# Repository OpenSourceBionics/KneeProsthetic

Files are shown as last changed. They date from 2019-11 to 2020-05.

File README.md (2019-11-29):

# KneeProsthetic

Passive and powered leg prostheses are expensive and require access to specific equipment and technology, making them very inaccessible. Our objective is to build an open source powered prosthesis that is lightweight, inexpensive, and has a functional controller to be a foundation for striving engineers.

## Getting Started

This repository contains the preliminary code to manually control your powered prosthesis through both wired and wireless communication. 

### Prerequisites

* Arduino - latest edition
* Teensyduino - latest edition
* Python 2.7

* Raspberry Pi Zero W (x2 for wireless communication)
* Teensy 4.0

### Installing

* [Teensyduino Download Link](https://www.pjrc.com/teensy/td_download.html)
* [Arduino Download Link](https://www.arduino.cc/en/main/software)

## Running the tests

Explain how to run the  tests for this system

## Authors

* **Justin Francis** - *Initial work* - [jphran](https://github.com/jphran)
* **Palani Thangaraj** - *Initial work* - [palan-thangaraj](https://github.com/palani-thangaraj)

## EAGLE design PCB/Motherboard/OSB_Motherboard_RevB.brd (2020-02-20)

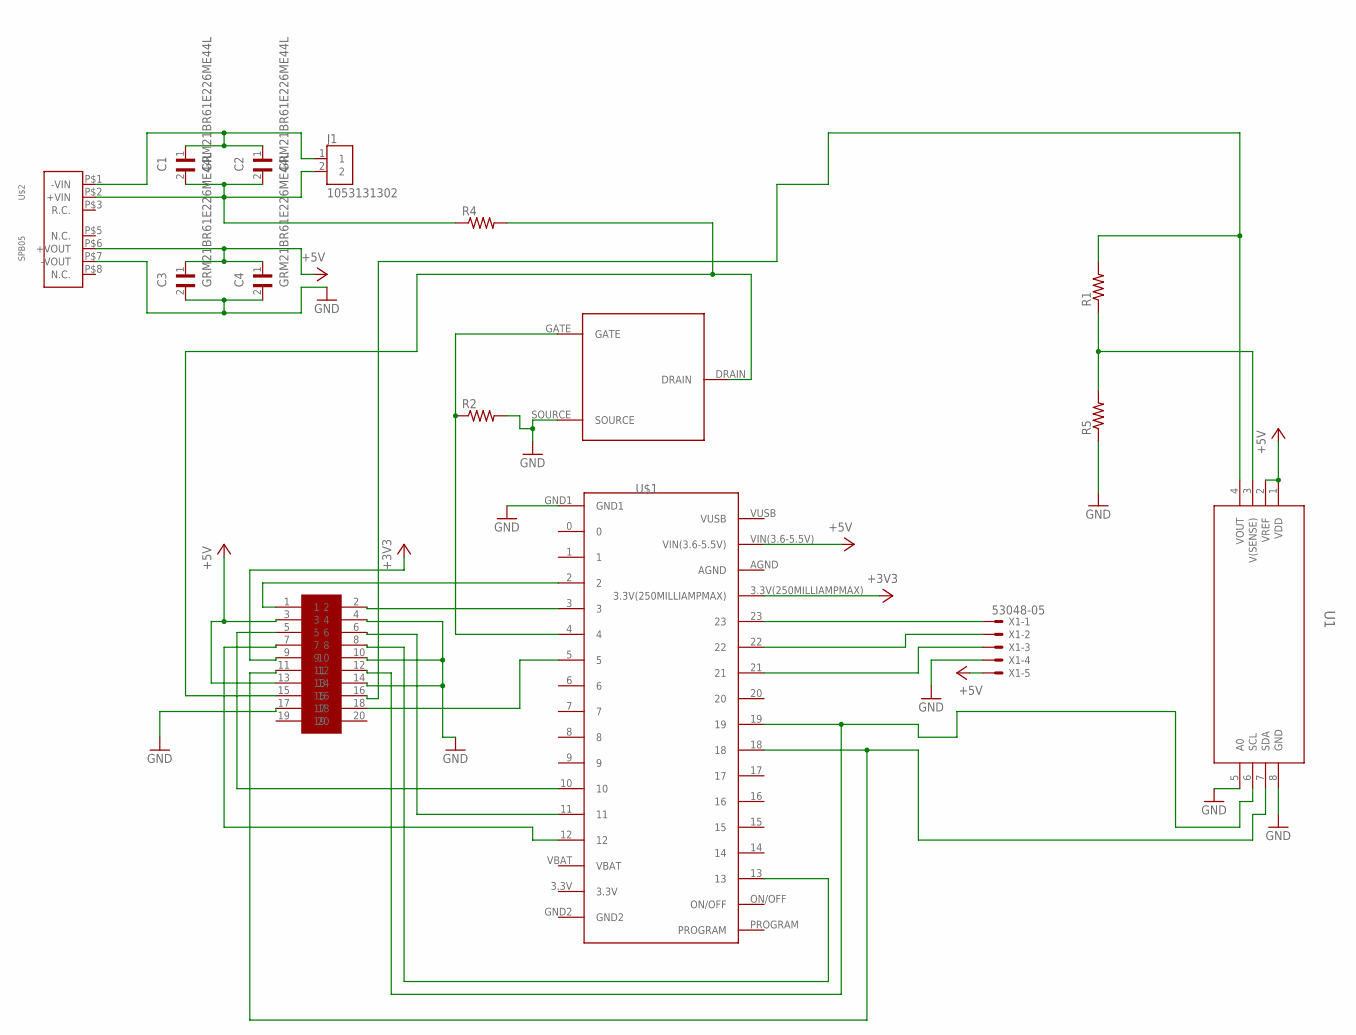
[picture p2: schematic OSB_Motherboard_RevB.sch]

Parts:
C1, C2, C3, C4: GRM21BR61E226ME44L; CAPC2012X135N
J1: 1053131302; MOLEX_1053131302
R1, R2, R4, R5: R-US_R0603; R0603
U1: DAC8571IDGKR; DGK8
U$1: TEENSEY4.0
U$2: SPB05; SPB05B-05
U$3: MGSF1N02L
U$4: MOLEX-PICOCLASP-2CIR
X1: 53048-05

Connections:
+3V3: U$1.3.3V(250MILLIAMPMAX), U$4.9
+5V: C3.1, C4.1, U1.1 (VDD), U1.2 (VREF), U$1.VIN(3.6-5.5V), U$2.P$6 (+VOUT), U$4.3, U$4.13, X1.5
GND: C3.2, C4.2, R2.2, R5.1, U1.5 (A0), U1.8 (GND), U$1.GND1, U$2.P$7 (-VOUT), U$3.SOURCE, U$4.4, U$4.10, U$4.14, U$4.17, X1.4
unnamed: U$1.2, U$4.1
unnamed: U$1.23, X1.1
unnamed: U1.6 (SCL), U$1.19, U$4.12
unnamed: U1.7 (SDA), U$1.18, U$4.11
unnamed: U$1.11, U$4.6
unnamed: U$1.3, U$4.2
unnamed: U$1.13, U$4.8
unnamed: U$1.22, X1.2
unnamed: U$1.21, X1.3
unnamed: U$1.12, U$4.7
unnamed: C1.1, C2.1, J1.1, U$2.P$1 (-VIN)
unnamed: U$1.10, U$4.5
unnamed: R1.1, R5.2, U1.3 (V(SENSE))
unnamed: R1.2, U1.4 (VOUT), U$4.16
unnamed: R2.1, U$1.4, U$3.GATE
unnamed: R4.2, U$3.DRAIN, U$4.15
unnamed: C1.2, C2.2, J1.2, R4.1, U$2.P$2 (+VIN)
unnamed: U$1.5, U$4.18

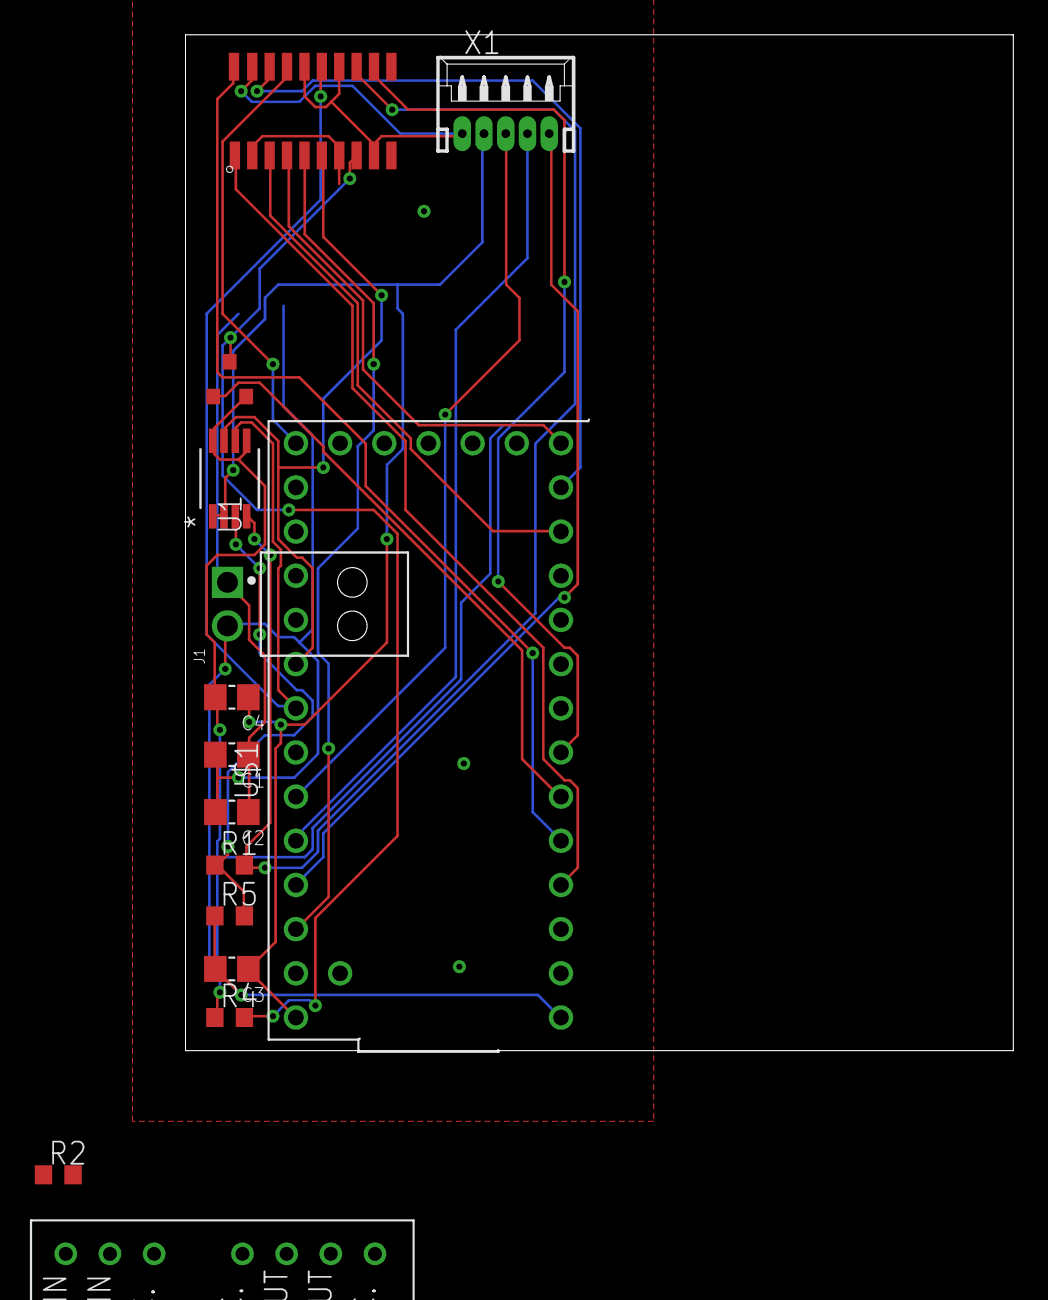
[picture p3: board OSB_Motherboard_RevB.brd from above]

Board: 2 copper layers, 47.6 x 58.4 mm, 15 parts (0 on the bottom side), 21 nets.

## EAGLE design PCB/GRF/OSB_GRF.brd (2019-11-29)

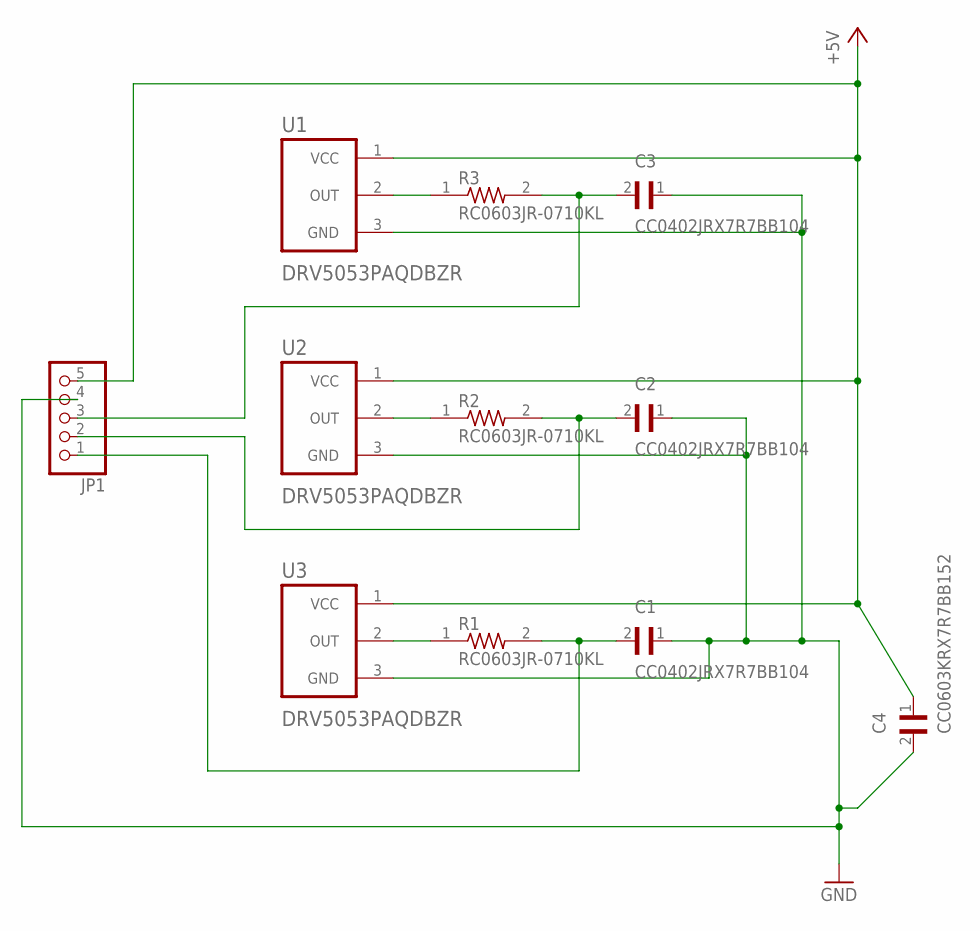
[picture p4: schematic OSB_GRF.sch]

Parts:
C1, C2, C3: CC0402JRX7R7BB104; CAPC1005X55N
C4: CC0603KRX7R7BB152; CAPC1608X90
JP1: PINHD-1X55X2MM; 1_05X2MM
R1, R2, R3: RC0603JR-0710KL; RESC1607X60N
U1, U2, U3: DRV5053PAQDBZR; SOT95P237X112-3N

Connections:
+5V: C4.1, JP1.5, U1.1 (VCC), U2.1 (VCC), U3.1 (VCC)
GND: C1.1, C2.1, C3.1, C4.2, JP1.4, U1.3 (GND), U2.3 (GND), U3.3 (GND)
unnamed: R1.1, U3.2 (OUT)
unnamed: R2.1, U2.2 (OUT)
unnamed: R3.1, U1.2 (OUT)
unnamed: C1.2, JP1.1, R1.2
unnamed: C2.2, JP1.2, R2.2
unnamed: C3.2, JP1.3, R3.2

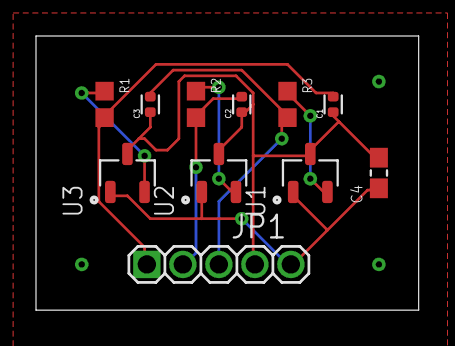
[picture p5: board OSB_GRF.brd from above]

Board: 2 copper layers, 21.3 x 15.2 mm, 11 parts (0 on the bottom side), 8 nets.

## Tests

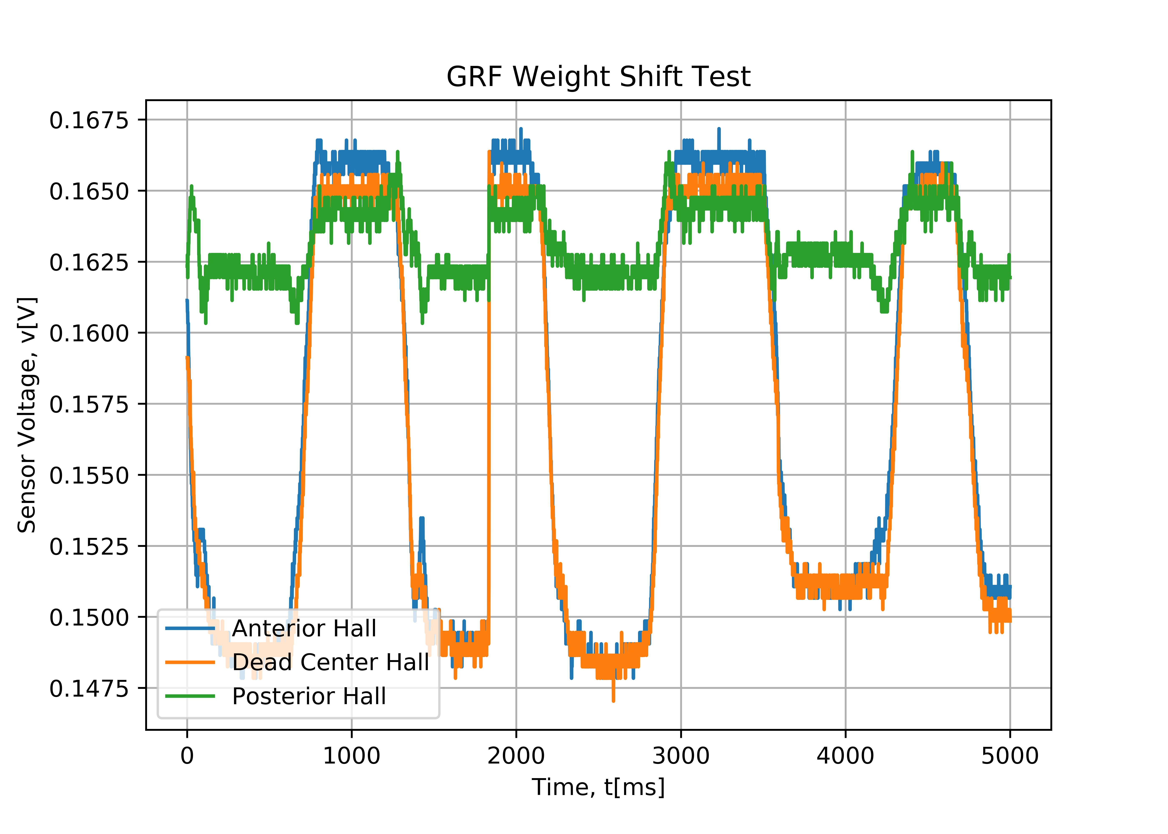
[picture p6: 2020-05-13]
Verification/verifyingHallEffectWDataLogger/GRF_Data.png

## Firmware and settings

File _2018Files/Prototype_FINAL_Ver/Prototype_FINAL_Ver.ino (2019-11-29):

#include "encoder_functions.h"
#include "motor_functions.h"
#include "joystick_functions.h"
#include "pid_functions.h"

#define ANGLE_OFFSET 0
#define BTN_PIN 2
#define N 10 // Rolling average parameter (angle filtering)
#define ALPHA 0.25 // IIR_WA filter parameter


float angle_lim[2] = {90, 165};

// Control Flow function declarations
void sense();
void process();
void actuate();

// Filtering functions
float iir_filter(float actual, float last_est, float alpha);
float rolling_avg_filter(float actual, float *last_ests, int n);

// Reference and input variables
float setpoint = 0; //[deg] desired position
float input = 0;
bool done = false;

// Time variables
unsigned long long duration = 5000;
unsigned long long start_time = 0;
unsigned long long last_time = 0;
unsigned long long time = 0;
unsigned long long refresh_time = 0;
unsigned long long refresh_period = 4000;
float dt = 0;

// Encoder angle variables
float raw_angle = 0;
float last_angle = 0;
float angle = 0;

// Encoder angle-rate variables
float last_speeds[N] = {0};
float speed = 0;

// Joystick measurement variables
int joystick_x = 0;
int joystick_y = 0;
bool joystick_btn = 0;

// Button state
bool btn_pressed = false;

// Error variables (angle diff)
float err = 0;
float last_err = 0;
float err_dot = 0;

void setup() {
  Serial.begin(9600);
  // Init hardware
  motor_init();
  spi_init();
  joystick_init();

  // Init button and led
  pinMode(BTN_PIN, INPUT_PULLUP);


  // Quickly record and process position data to bring filter to equilibrium
  for (int i = 0; i < 20; i++) {
    sense();
    process();
    delay(30);
  }
  done = false;
  Serial.printf("Current angle: %f\n", angle);
  /*Serial.println("Enter angle for setpoint.");
  while (Serial.available() <= 0);
  setpoint = (float)Serial.parseInt();
  Serial.printf("Setpoint of %.1f deg chosen\n", setpoint);
  */
  Serial.println("Test Begin");
  for (int i = 0; i < 3; i++) {
    sense();
    process();
    delay(30);
  }
  done = false;

  ////   Give the motor power and start the clock
  enable();  
  start_time = millis();
  //  Serial.print("data = [");
}

void loop() {
  sense();
  process();
  actuate();
  Serial.print(joystick_x);
  Serial.print(' ');
  Serial.print(input);
  Serial.print(' ');
  Serial.println(get_angle());
  delay(20);
  ////  Serial.printf("%u,%f,%f,%f,%f;\n", time - start_time, setpoint, angle, err, input);
  //
  //  // Stop when process is finished
  //  // (done is defined as true in process() when finished)
  //  if (done) {
  //    disable(); // Disable motor, kill the power
  //    Serial.print(']');
  //    while (true);
  //  }
}

/*===================================================================*
   ---------------------- FUNCTION DEFINITIONS ----------------------
  ===================================================================*/

/*
   Measure encoder angle, button state, joystick state, and record time
*/
void sense() {
  // Get measurements from each instrument
  float measurement = get_angle();
  bool btn_read = digitalRead(BTN_PIN);
  int joystick_data[3] = {0};
  measure_joystick(joystick_data);

  // Check for validity of encoder data
  if (measurement)
    raw_angle = measurement;

  // Update button var
  btn_pressed = !btn_read; // Invert btn_read so 1 is pressed, 0 is unpressed

  // Unpack joystick data
  joystick_x = -joystick_data[0];
  joystick_y = joystick_data[1];
  joystick_btn = !joystick_data[2]; // Invert btn so 1 is pressed, 0 is unpressed

  // Update timestamps
  last_time = time;
  time = millis();
}

/*
    Post-process the current data
*/
void process() {
  // IIR filter the angle
  last_angle = angle;
  angle = iir_filter(raw_angle - ANGLE_OFFSET, last_angle, ALPHA);

  // Calculate angular rate from measurement
  long long DT = time - last_time;
  dt = (float)DT / 1000; // Convert to seconds
  float raw_speed = (angle - last_angle) / dt;

  // Update array of speed history
  for (int i = 0; i < N - 1; i++)
    last_speeds[i] = last_speeds[i + 1];
  last_speeds[N - 1] = speed;
  // Use speed history to filter speed reading
  speed = rolling_avg_filter(raw_speed, last_speeds, N);

  // PID controller
  //  // Calculate errors
  //  last_err = err;
  //  err = setpoint - raw_angle;
  //  err_dot = (err - last_err) / dt;
  //
  //  // Determine if program has run for full duration
  //  if ((millis() - start_time) >= duration)
  //    done = true;

  // Determine motor input from pd controller
  //  input = constrain(pd(dt, err_dot, err), -255, 255); //PD

  // Joystick Controller
  int max_input = 255;
  input = mapFloat(joystick_x, -515, 515, -max_input, max_input);
  input = constrain(input, -max_input, max_input);
  if (angle >= angle_lim[1] && input >= 0)
    input = 0;
  else if (angle <= angle_lim[0] && input <= 0)
    input = 0;
}

void actuate() {
  set_speed(input);
}
  //iir filter
float iir_filter(float actual, float last_est, float alpha) {
  return alpha * actual + (1 - alpha) * last_est;
}
  // rolling average filter
float rolling_avg_filter(float actual, float *last_ests, int n) {
  float est = actual;
  for (int i = 0; i < n; i++)
    est += last_ests[i];
  est /= n;
  return est;
}

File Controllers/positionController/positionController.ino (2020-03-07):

/*
 * Auth: Justin Francis
 * Date: 2/21/20
 * Ver: 0.1
 * Sum: Finite state machine: Stance (binary), Swing (PID). 
 * Mod:
 *    
*/

#include <Arduino.h>
#include <SPI.h>
#include <Wire.h>
#include <math.h>



#define ABSPIN 10 //abs enc cs pin
#define ANGLECOM 0x3FFF //abs enc register that returns measured angle with dynmic angle err compensation
//empirically determined speed curve (x = thetaDotDes [rad/s], y = command voltage[rad/s])
#define MOT_CONTROL_CURVE (0.67 - 0.148*log(abs(thetaDotDes))) 

//teensy 3.2 limits
#define DAC_RES 1023 //10 bit
#define DAC_MAX 3.3 //[V]
#define MOT_MIN_CMD 3.3 //[V]
//as read from abs enc
#define EXTENSION_MAX 298.2 //[deg]
#define FLEXION_MAX 10 //[deg]
#define INPUT_MAX 1.20 //[rad]

SPISettings kneeSettings(10e6, MSBFIRST, SPI_MODE1);

//IMU stuff
const int IMU = 0x68; //i2c addy
const int ACCEL_XOUT_H = 0x3B; //x accelerometer addy
const int ACCEL_RES = 16384.0; //14 bits

float AccX, AccY, AccZ;
float GyroX, GyroY, GyroZ;
float accAngleX, accAngleY, gyroAngleX, gyroAngleY, gyroAngleZ;
float roll, pitch, yaw;
float AccErrorX, AccErrorY, GyroErrorX, GyroErrorY, GyroErrorZ;
float elapsedTime, currentTime, previousTime;
int c = 0;

//control vars
float P = 30; //proportional gain K_u ~= 35
float k; //conversion factor for theta dot to voltage for the controller output
float motCmd; //value to output to motor controller
float err; //controller error
float thetaDes = 0; //desire joint position [rad]
float theta, thetaDotDes; //joint position [rad], desire joint velocity [rad/s]

//motor vars
const int DAC_Pin = A14; //motor speed pin
const int directionPin = 5; 
const int enablePin = 4;

//fn prototypes
void MotorDrive(float thetaDotDes);
int8_t finiteStateMachine(float *GRF, float *IMU, uint32_t incEnc);
void stanceController(void);


void setup()
{
    Serial.begin(115200);
    //enable motor
    pinMode(DAC_Pin, OUTPUT);
    pinMode(directionPin, OUTPUT);
    pinMode(enablePin, OUTPUT);

    
    //this is needed for the motor startup sequence
    digitalWrite(enablePin, LOW);
    delay(2);

    //enable spi
    SPI.begin(); //this inits all spi pins on teensy and pulls sck/mosi low and ss HIGH
    pinMode(ABSPIN, OUTPUT);
    digitalWrite(ABSPIN, HIGH);

    //enable IMU
    Wire.begin();   // Initialize comunication
    Wire.setClock(4e5); //fast mode                   
    Wire.beginTransmission(IMU);       // Start communication with IMU6050 // IMU=0x68
    Wire.write(0x6B);                  // Talk to the register 6B
    Wire.write(0x00);                  // Make reset - place a 0 into the 6B register
    Wire.endTransmission(true);        //end the transmission

}



unsigned int absData = 0;
float angle;
void loop()
{
    //read abs enc
    SPI.beginTransaction(kneeSettings);
    digitalWrite(ABSPIN, LOW);
    absData = SPI.transfer16(ANGLECOM);
    digitalWrite(ABSPIN,HIGH);
    
    //convert data to angle 
    absData = (absData & (0x3FFF)); 
    angle = ( (float) absData * 360.0 / 16384.0); //[deg]
    //angle conditioning
    if(angle >= EXTENSION_MAX){
        angle -= EXTENSION_MAX;
    }
    else if(angle <= FLEXION_MAX){
        angle += (360.0 - EXTENSION_MAX);
    }
    else{
        while(1){
            //TODO: need to program some sort of reset or get the other encoder working
            //stop motor
            MotorDrive(0.0);
        }
    }
    //convert to rad
    theta = angle * PI/180; //[rad]
    Serial.print("angle: ");Serial.println(theta);


    // === Read acceleromter data === //
    Wire.beginTransmission(IMU);
    Wire.write(ACCEL_XOUT_H); // Start with register 0x3B (ACCEL_XOUT_H)
    Wire.endTransmission();
    Wire.requestFrom(IMU, 6, true); // Read 6 registers total, each axis value is stored in 2 registers
    //For a range of +-2g, we need to divide the raw values by 16384, according to the datasheet
    AccX = (Wire.read() << 8 | Wire.read()) / 16384.0; // X-axis value
    AccY = (Wire.read() << 8 | Wire.read()) / 16384.0; // Y-axis value
    AccZ = (Wire.read() << 8 | Wire.read()) / 16384.0; // Z-axis value

    float IMUdata[] = {AccX, AccY, AccZ};
    float GRF[3];
    uint16_t incEnd = 0;
    Serial.print("state: ");Serial.println(finiteStateMachine(IMUdata, GRF, incEnc));

}

/*
 * function to control the motor, takes in a desired velocity and commands the motor
 * no return
*/
void MotorDrive(float thetaDotDes)
{
    if(thetaDotDes >= 0.0)
    {
        digitalWrite(directionPin, HIGH);
    }
    else
    {
        digitalWrite(directionPin, LOW);
    }
    
    digitalWrite(enablePin, HIGH);
    motCmd = MOT_CONTROL_CURVE; //[V]
    Serial.print("Motcmd: ");Serial.println(motCmd);
    motCmd = constrain(motCmd, 0.0, MOT_MIN_CMD); //anything outside of this voltage range cause the controller to pause

    analogWrite(DAC_Pin, (int)(motCmd*DAC_RES/DAC_MAX)); //convert command into voltage
}

/*
 * takes in GRF, IMU, and returns the state
 * stance == 0
 * swing == 1
 * undef == -1
*/
int8_t finiteStateMachine(float *GRF, float *IMU, uint16_t incEnc){
    //indices to trigger around
    const uint8_t antGRF = 0;
    const uint8_t postGRF = 1;
    const uint8_t deadGRF = 2;
    //will only need 1
    const uint8_t sagAcc = 0;
    const uint8_t transAcc = 1;
    const uint8_t coronAcc = 2;
    const float stanceThres = 0.174533; //[rad]
    //will only need 1
    const uint8_t sagGyro = 0;
    const uint8_t transGyro = 1;
    const uint8_t coronGyro = 2;


    //find thigh angle
    float thighAngle = atan(IMU[coronAcc]/IMU[transAcc]); //[rad]

    // if thigh angle <= Stance, return stance 
    if(thighAngle <=  standThres){
        return 1;
    }
    else{return 0;}
    //else return swing

}



/*
 * tightens knee to full extension end stop 
 */
void stanceController(void){
    
}

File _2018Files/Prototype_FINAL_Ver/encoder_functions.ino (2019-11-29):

#include <SPI.h>
#include "encoder_functions.h"

void spi_init() {
  pinMode(CSN, OUTPUT);
  pinMode(SI, OUTPUT);
  pinMode(SO, INPUT);
  pinMode(CLK, OUTPUT);
  
  // Set slave select high to start. i.e disable chip
  digitalWrite(CSN, HIGH);
  SPI.begin();
}

float get_angle() {
  unsigned int angle;
  SPI.beginTransaction(SPISettings(10000000, MSBFIRST, SPI_MODE1));
  
  //Send the Command Frame
  digitalWrite(CSN, LOW);
  delayMicroseconds(1);
  SPI.transfer16(0xFFFF);
  digitalWrite(CSN,HIGH);

  //Read data frame
  digitalWrite(CSN, LOW);
  delayMicroseconds(1);
  angle = SPI.transfer16(0xC000);
  digitalWrite(CSN, HIGH);
  SPI.endTransaction();

  angle = (angle & (0x3FFF)); 
  float pos = ( (float) angle) * 360.0 / 16384.0;
  return pos;
}

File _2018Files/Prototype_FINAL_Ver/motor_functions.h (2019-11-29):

#define PINK_PIN  23
#define RED_PIN   19
#define BLUE_PIN  21
#define GREY_PIN  A14
#define ANALOG_RES 12

// Opperational parameters
#define DEAD_ZONE 1.5f
#define DEAD_TIME_MS 1

// Motor Functions
void init();
void set_voltage(float volt);
void set_direction(bool dir);
void set_speed(float speed);
float speed_to_voltage(float speed);
void enable();
void disable();
void enable_speed();
void disable_speed();

// Test Functions
void btn_wait();

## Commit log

2019-10-25 updated test file for motor lib
2019-10-29 added hall effect
2019-11-01 added int 3 hall effects
2019-11-01 merging in 3 hall sensors
2019-11-06 modified for teensy 3.6
2019-11-08 can't read the abs enc. need to try a new sensor
2019-11-09 broken incEnc lib, cannot link to lib headers through #include
    [AbsEncoder.cpp, GRF.cpp, GRF.h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]
2019-11-11 added schematics
    [OSB_GRF.brd, OSB_GRF.sch]
2019-11-12 finished OSB_GRF
    [OSB_GRF.brd]
2019-11-12 all sensors work, need to figure out libs
2019-11-14 added motherboard schematic
    [OSB_GRF.brd, OSB_GRF.sch, OSB_Motherboard_RevA.brd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]
2019-11-15 added in motherboard RevB, working on motor char
2019-11-16 fixed motor.cpp
2019-11-17 added in motor char files, working on position p controller
    [FindingMaxOmega.csv, FindingMaxVoltageCmd.csv, FindingVoltageCmd.csv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]
2019-11-17 added pd and pid controller, both are fairly unstable. need to tune. need to see if they're implemented correctly
    [stepResponse.ino, velocityPD.ino, velocityPID.ino]
2019-11-17 added step response files. need to do this again with the digital motor reset setup
    [KpIs10.csv, KpIs20.csv, KpIs35.csv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]
2019-11-24 wireless communication code
2019-11-25 added in DAC verification code. does not work on mboard, need to probe i2c lines
    [verifyingDAC.ino]
2019-11-25 working hall effects, need to still figure out DAC
2019-11-26 working dac on teensy 3.2, working motherboard with 3.2
2019-11-27 attempted walking with position p controller and pot... sheared shaft
2019-11-29 finialized pcb fil files
2019-11-30 fixed syntax in testingPcontroller
    [testingPcontroller.ino]
2019-12-01 spelling errors in testingPcontroller
    [testingPcontroller.ino]
2019-12-10 fixed motor command limitation voltage
    [testingPcontroller.ino]
2020-02-10 fixed abs enc constraint
    [potController.ino]
2020-02-20 working on motherboard Rev B
    [OSB_Motherboard_RevB.brd, OSB_Motherboard_RevB.sch]
2020-05-13 motor move
